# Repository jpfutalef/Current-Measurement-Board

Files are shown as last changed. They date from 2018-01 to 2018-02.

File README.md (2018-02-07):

# Power-Monitoring-Board
This repo contains scripts, details and specifications for a board designed to measure very low power consumption in MCU's with high accuracy.

## Goals

The goal here is to develop a simple current measuring board that can measure from 1uA - 50mA at high frequencies (>10kHz).

This board has to be easy to connect to a computer or a raspberry, minimizing cable connections. The idea is to have a single board with two usb ports, one to connect to the PC and the other to an IoT node with any usb connection (micro, mini, etc.).

## Organization

The repo is organized as follows,

* **ltspice**: in this folder can be found the different spice schematics to simulate the different current measurement boards.
* **scripts**: in this folder can be found different c, python, etc. scripts used to read data from the current measurement circuit or calibrate the respective board.
* **boards**: the actual eagle schematics can be found in this folder, either for the circuits or breakout's for small smd-components.

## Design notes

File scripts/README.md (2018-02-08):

# Scripts for usage in RIOT

These scripts are intended to be used with RIOT for power measurement using the power measurement board.

### adc_riot_test
Test RIOT's peripherial ADC, using a pause function to make a read with a fixed frequency. The user can set in the script the frequency, bit resolution, etc.

### arduino_ina226
INA226 IC was used to measure current with Arduino and the INA226_ADC.ino file inside this folder.

### power_measure
Necessary scripts for power measuring using the board. Includes a main file with makefile to flash into a micro-controller (Intended to be used with RIOT) and a master.py file to read values from computer via serial communication and make calculations.

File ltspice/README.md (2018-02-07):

# Spice models for power measurement boards
These spice models were used to simulate the behavior of the circuits before prototyping them. 

## About files
### v1_lmp2011_lt624X.asc
Simulates a LMP2011 based circuit. Uses LMP2011 as first stage. Uses LTC2041 for second stage in both ranges. Uses LTC2040 for supply buffer stage. Uses LT3461 as DC booster 8v68 supply for opamps.

### v1_ltc2055_lt624X.asc
Simulates a LTC2055 based circuit. Uses LTC2055 as first stage. Uses LTC2041 for second stage in both ranges. Uses LTC2040 for supply buffer stage. Uses LT3461 as DC booster 7V supply for opamps.

### v1_max4239_lt624X.asc
Simulates a MAX4239 based circuit. Uses MAX4239 as first stage. Uses LTC2041 for second stage in both ranges. Uses LTC2040 for supply buffer stage.

### v2_max4239_lt624X.asc
Added tolerance of more resistors, tries other shunt value. Reorganized and added labels for nodes.

### v3_max4239_lt624X.asc
Tries other shunt value. Changes stage gains to increase CMRR. Capacitor in SHDN now is connected to ground (as it should be).

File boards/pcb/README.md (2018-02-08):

## Power measurement boards

Until now, two board designs have been prototyped for the power measurement circuits, one based on LPM2011 op amp and the other one on MAX4239. This two IC were chosen because of their very low input offset voltage, both around 1uV or less in typical conditions. Also, both circuits in a similar fashion, this is detailed in the "How do they work" section.

Detailed design choices, specifications, BOM, versions, etc. are explained in the respective board folders.

## How do they work

### Current and voltage reading

It is very well known that for power measurement in circuits, voltage and current should be known.

Nowadays, analog-to-digital converters (ADC) are used widely to measure voltage, converting analog values in digital ones (bits), so they can be analyzed in a computer.

Current measurement is a bit harder, mainly because it's not possible to do it directly, instead, you should open the circuit, place a resistor (Shunt resistor) and, using Ohm's law, read the voltage across the Shunt to know the current.

After that, several subjects shall be considered:
- The voltage drop across the Shunt should not be too high, this can negatively impact in the supply of the circuit.

- It is better to isolate the voltage before an ADC input, these tend to produce peaks when a conversion is started changing the input impedance. A buffer amplifier stage might be placed.

- An important factor with ADC's are their least significant bit (LSB) value. That's the minimum voltage necessary to produce a reading in the ADC (one bit). It can also be considered as the ADC's resolution. The problem is that, when dealing with very low voltages, the LSB might be greater than the actual voltage that is intended to read, so the ADC will output a zero value. This can be solved by per-amplifying th ADC's input. The gain of the amplifier should be known so the actual reading can be computed.

- When dealing with very low currents, the voltage drop in the Shunt is also very low if the resistor is small. Just consider a 1 ohm resistor and 10 uA going trough it. According to Ohm's law, 10 uV will appear across the resistor leads. As it has been mentioned before, the LSB of the ADC might not be enough, so an amplifying stage should be placed. Here we have to deal with amplifiers limitations, specially input offset voltage. This is the voltage that appears between the differential inputs of the amplifiers when nothing is connected and depends among others on transistor paring in the ADC IC. A very precise op-amp should be chosen, with very low input offset voltage, like an auto-zero opamp.

- CMRR of opamp should also be considered, because for small currents the voltage across the shunt might have a very low common mode side that should be rejected. This can be solved with a configuration that produces a very high CMRR (120 dB or more) like instrumentation opamps. Never the less one must also be careful with the preición of the resistors used to define the opamp gain, as CMRR will be limited by the following expression:

<div align="center">
<a href="http://www.codecogs.com/eqnedit.php?latex=CMRR&space;=&space;\dfrac{A_d&plus;1}{4t}" target="_blank">CMRR = \dfrac{A_d+1}{4t}</a></div>

Where Ad is the differential gain of the amplifier and t the tolerance. It has been concluded that 0.1% tolerance resistor or more are OK.

### MAX4239 and LMP2011 boards

As explained above, amplifying stages and very low input offset voltage opamps are needed. The two boards proposed here use a very low input offset opamp in a first stage with differential configuration. A second stage uses a different opamp, with bigger input voltage but less noise.

This second stage takes the output of the first stage and amplifies depending of the current range. For very low current there is a high gain amplification and for high current a low gain amplification. Both amplification configurations of the second stage are implemented with a dual opamp (LTC6241) with very low noise. After this second stage an ADC measures the voltage that can be interpreted as a current measurement.

Due to the wide range of supply voltages that can power the target circuit, an ADC reads the voltage of the supply. For isolation, a buffer reducing stage is placed at the supply. This stage lowers the voltage 1/2 times so it can be read by an ADC with 3.3V reference, therefore the circuit could also properly read 5V supply.

### Calibration

Even though this opamps have very low input voltage, with very low currents (5uA or less) the voltage drop in the shunt has the same order of magnitude as it's offset.

A set of calibration resistors are used to emulate the conversion of low current values and after establish a piecewise approximation for these voltage ranges. This is why there are 4 fixed resistor values (1k, 10k, 100k and 1M) and 4 analog switches.

There is also an analog switch that allows the flow of current trough the target circuit. The purpose of this switches is to make a calibration of the readings before using the board, by not allowing current flow trough the target circuit and connecting the resistors one by one.

### High-side current measurement and low-side current measurement

Depending of the configuration, the shunt resistor could be placed at the top, just after the supply (high-side current measurement) or at the bottom, just before ground (low-side current measurement). In this case, high-side current measurement has been chosen because it does not intervene the ground path of the circuit.

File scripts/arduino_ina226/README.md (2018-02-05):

## Simple INA226 test

This file contains a library to test INA226. This IC was initially considered to measure current, voltage and power.

### Benefits of INA226

The ina226 has everything integrated into 1 IC (current measuring circuit, ADC & i2c interface) which makes it easy to connect and setup.

### Limitations of INA226

The fact that it only has an integrated ADC limits the resolution for this IC to the defined gain for the single transimpedance amplifier stage. For example assuming 5V supply for the ADC and a max current on 100mA max resolution would be of 15,23 uA/LSB. Plus the voltage input range is fixed at -81.8175 mV to 81.92 mV this limits the shunt resistor value.

Although having great features we miss in this IC the possibility to connect an extra gin stage to have better resolution for lower current ranges, this is why this IC was finally discarded.

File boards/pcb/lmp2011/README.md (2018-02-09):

# PCB eagle schematics and boards for LMP2011

LMP2011 is a precision OPAMP. This device uses auto-zero techniques to continually correct the input offset error voltage. The input offset is 60uV in the worst case scenario,  0.8uV typically. Furthermore has a typical CMRR of 130dB, its minimum is 95dB.

## Notations
* Current Measuring Board (CMB): PCB with the designed circuit that can measure shunt voltage, and supply voltage.
* mcu: microcontroller connected to the CMB, its performs calibrations and translate the supply voltage and current measurements.
* Node: target mcu which power consumption the CMB is measuring.

## How to use

* Connect switch controllers (SWITCH_CTRL_1 to SWITCH_CTRL_5) to 5 different GPIO on any mcu.
* Connect low current, high current and supply voltage to 3 different ADC input in the mcu
* Power the CMB, either from the micro usb port or with 5V from an external power supply
* Bypass the targeted node power supply by either connecting it's power source to VBAT or the USB port on CMB.
* If the targeted node supply source is connected to VBAT then the node can be powered by connecting it's power input to VMCU, if it's USB powered a jumper must be connected between 5V and VBAT on CMB.

## Specifications:
- Power supply: 5V from USB port
- Current range: ~10uA - 50mA
- First stage gain: x100
- Second stage gain: x197 for low current, x1.51 for high current

## How version 2 works(detailed)

This board has a similar operation as the design using MAX4239, except that in this case the CMB does not include a DC booster (TODO: check if it is neccesary).

### Fist stage

The first stage amplifies the voltage difference in the shunt resistance through an OPAMP. R1, R2, R4 and R5 form a x100 gain between VBAT y VS-. R27 and C2 are added for stability purposes. 

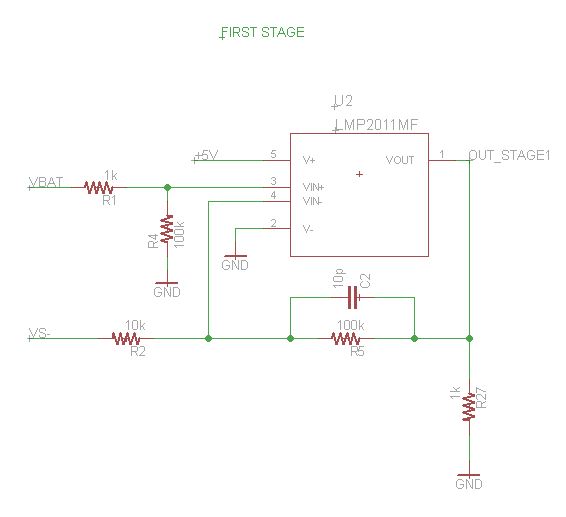
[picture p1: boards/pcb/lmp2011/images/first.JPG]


### Second stage

The second stage has a LTC6241 high precision dual opamp. There are two current ranges with different gains:

- Low current range: 0uA-600uA, x197 gain
- High current tange: 600uA-50mA, x1.51 gain

These gains values adjust to the ADC input ranges. The 49.9 resistor are put in place to isolate the amplifier output and ADC input, thus preventing oscillation.

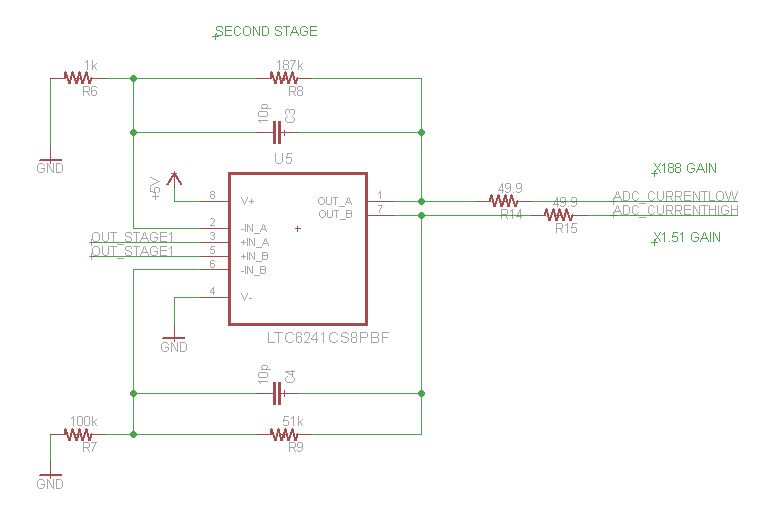
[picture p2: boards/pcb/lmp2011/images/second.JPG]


4 usually open analog switches are used for calibration in low current, this is done by measuring current flow threw resistors R9, R10, R13 and R14. TS5A23166DCUR switches where chosen for their high voltage input range, high max current and low Ron (0.8 ohms).

A normally closed switch is connected between the target node and it's supply source. The TS5A23167DCUR was chosen with similar characteristics as the TS5A23167DCUR.

C1 capacitor is connected between the supply source and ground to stabilize supply voltage from power source.

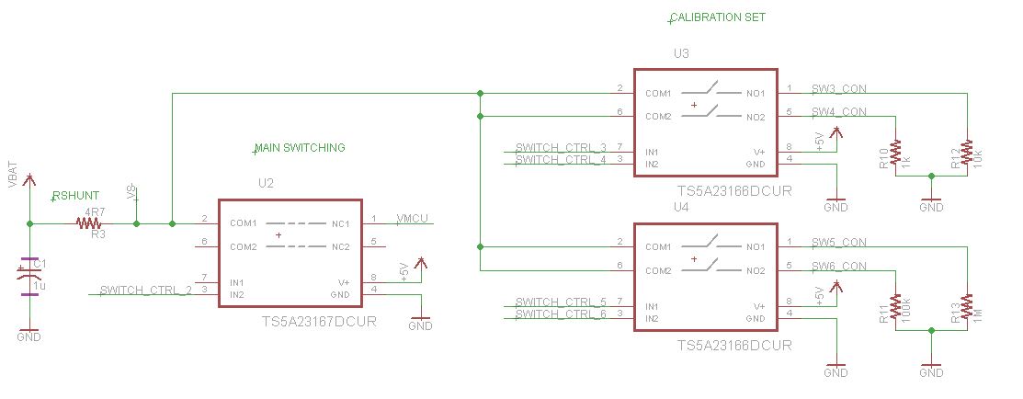
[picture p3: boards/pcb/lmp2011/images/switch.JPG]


The buffer stage to measure the supply source uses a LTC6240 high precision amplifier with a x0.5 gain stage to allow supply voltage higher than the mcu supply (3.3V) to be converted with the ADC. This buffer stages also isolated the two.

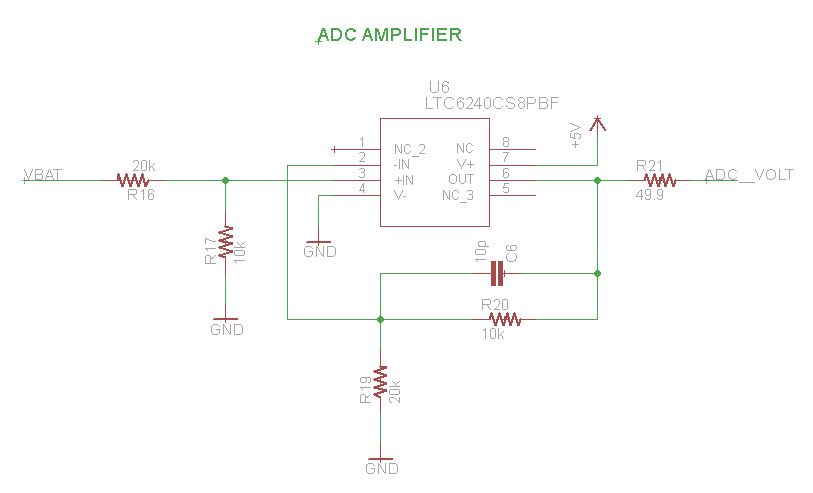
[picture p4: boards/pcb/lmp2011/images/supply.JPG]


As a supply source a microUSB type B female connector is used. This gives a 5V power supply. To reduce high frequency noise a high impedance, low frequency ferrite is used (1K@1Mhz).

A female type A USB connector can be used to power the targeted node. Analog and digital ground are separated by using two schottky diodes, CUS08F30 because of their high response and low activation voltage.

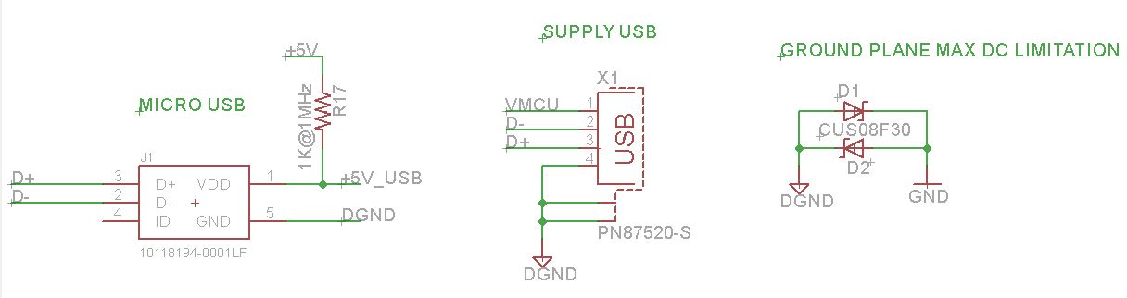
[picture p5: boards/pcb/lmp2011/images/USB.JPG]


### Available connections

Multiple input/output pins are exposed to users: 

- SWITCH_CTRL_1: switch's on power supply for targeted node.
- SWITCH_CTRL_2 a 5: switches on or off calibration resistors.
- VMCU: output voltage that powers the targeted node it's short-circuited to the female type A USB.
- GND: ground
- OUT_STAGE1: first amplifying stage gain output, for debugging purposes.
- VS-: shunt resistor low voltage pin.
- VBAT: pin where targeted node supply voltage is connected to bypass it.
- +5V: 5V output, its separated from the USB by the ferrite. de 5V, separada de USB por la ferrita.

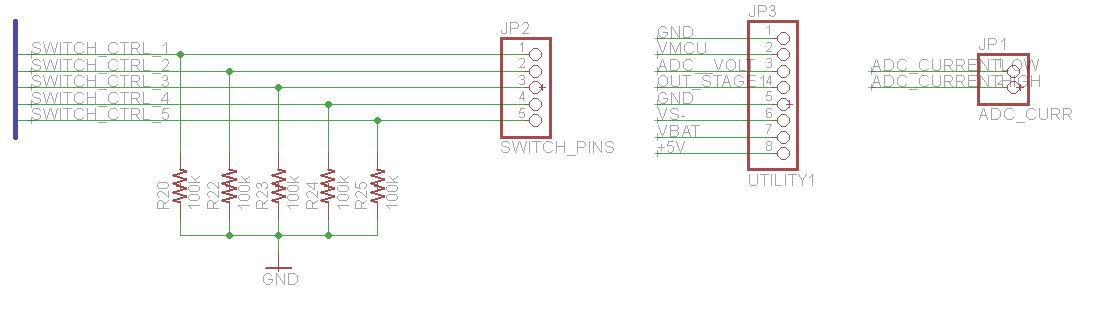
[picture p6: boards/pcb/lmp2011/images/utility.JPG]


# Board versions

## LMP2011 V1 - Fabricated
This version of the board was manufactured with [OSHPARK](https://oshpark.com/). Soldering and testing was done at Inria Chile office.

### Overview

This board needs a 5V supply for most of the IC, LMP2011 get supply from a DC booster in the CMB.

The first stage is a differential amplifier with x10 gain, the second stage has a low current stage with x197 gain and a high current range with x1.51 gain.

To read supply voltage a x0.5 buffer stage is used.

Analog and digital ground are separate with schottky diodes.

5V supply source is filtered with a 1k@1MHz ferrite.

USB enclosure is connected to the digital ground.

### Testing conclusions

#### Remarks
- Manufactured board
- Soldered components
- All IC had correct supply and GND connections
- There is an error in power supply for the LMP2011 design: it can't be supply from 8v68. MIC2250 is not connected and bypass 5V to the supply pin of the IC.
- There aren't conclusive results from the circuit. The CMB with this IC does not work as it should, neither in a breadboard.

#### TODO
- Check connections in LMP2011
- Check real measurement range
- Make reading with a mcu. Calibrate and control of the switches

#### Issues
- LMP2011 not working correctly
- The gain in low current stage should be x197, not x19.7 10K resistance should be a 1K
- Control switch for node supply are not connected well. This was fixed soldering directly from the inputs of the switch
- Ad
- VBAT and VADC silkscreen names are misplaced, they are switched.
- There are no pull-down resistors in the control switch

#### To improve
- CMRR by using higher tolerance resistor values, at least 0.1%. This can also be done by incrementing the stages gain, but this affects the current ranges
- Change USB port from SMD to thru-hole to improve robustness in the pcb
- Different configurations for the first stage should be considered

## LMP2011 V2 - not manufactured

This version of the board should solve the issues from the last version manufactured.

* Remove DC booster (Check supply needed from the IC)
* Low current gain is addressed by changing 10K resistors to 1K
* Switch connection is fixed
* Pull down resistors are included for the switches

There is only the schematic for this board, not the board design yet

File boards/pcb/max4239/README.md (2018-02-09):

# PCB eagle schematics and boards for MAX 4239

MAX4239 is a auto-zero amplifier, with low input voltage offset of 1.0uV (typical) and 2uV (full temp range), it also has a high CMRR of 120dB (min), 140dB (typ).

### Notations
* Current Measuring Board (CMB): PCB with the designed circuit that can measure shunt voltage, and supply voltage.
* mcu: microcontroller connected to the CMB, its performs calibrations and translate the supply voltage and current measurements.
* Node: target mcu which power consumption the CMB is measuring.

### How to use

* connect switch controllers (SWITCH_CTRL_1 to SWITCH_CTRL_5) to 5 different GPIO on any mcu.
* connect the low current, high current and supply voltage output to 3 different ADC inputs on your mcu.
* power the CMB by either connecting it to it's microUSB port ore the 5V supply pin.
* bypass the targeted node power supply by either connecting it's power source to VBAT or the USB port on CMB.
* if the targeted node supply source is connected to VBAT then the node can be powered by connecting it's power input to VMCU, if it's USB powered a jumper must be connected between 5V and VBAT on CMB.

### Ratings V2:
- Power supply: 5V from USB port
- Current range(ideal): ~1uA - 50mA
- First stage gain x10
- Second stage gain x197 for low currents and x1.51 for high currents.

### Ratings V3:
- Power supply: 5V from USB
- Current range(ideal): ~1uA - 50mA
- First stage gain x100
- Second stage gain x19.7 for low currents and x0.151 for high currents.

### MAX4239 V3 (detailed)

The first stage amplifies the voltage measured at the shunt by applying a differential gain. R1, R2, R4 & R5 form a x100 gain. R6 and C3 are added for stability, C3 also helps to reduce currents peaks. C2 stabilizes the power supply.

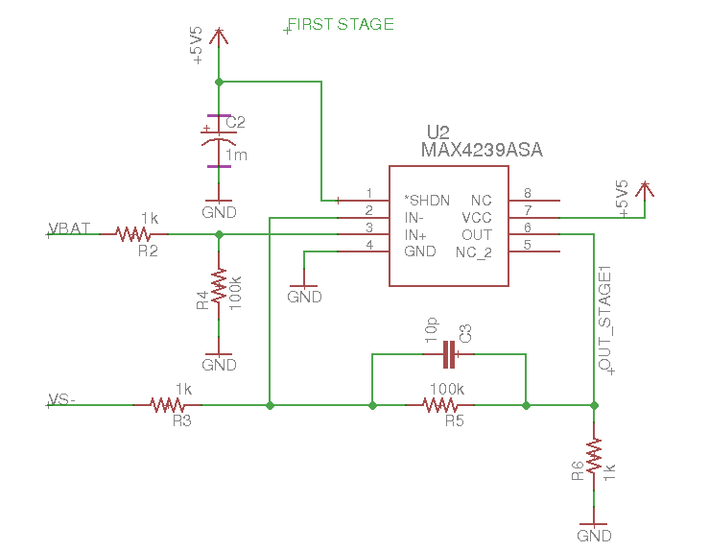
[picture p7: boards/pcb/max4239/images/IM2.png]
max4239_gain_stage


The second stage is conformed by a dual LTC6241 high precision opamp. There are two current ranges with to different gains:

- Low current range: 0uA-600uA, x197 gain
- High current range: 600uA-50mA, x 1.51 gain

These gains values adjust to the ADC input ranges. The 49.9 resistor are put in place to isolate the amplifier output and the ADC input, thus preventing oscillation.

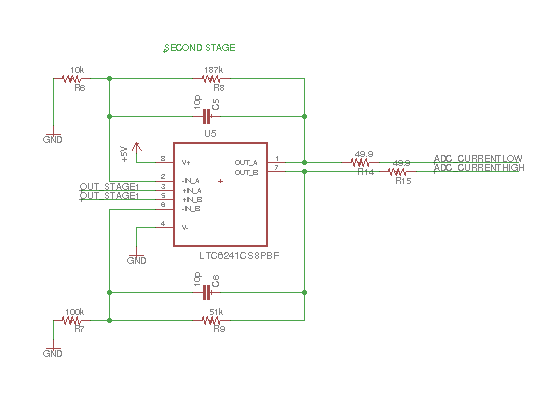
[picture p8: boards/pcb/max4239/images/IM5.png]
ltc6241_gain_stage


4 usually open analog switches are used for calibration in low current, this is done by measuring current flow threw resistors R9, R10, R13 and R14. TS5A23166DCUR switches where chosen for their high voltage input range, high max current and low Ron (0.8 ohms).

A normally closed switch is connected between the target node and it's supply source. The TS5A23167DCUR was chosen with similar characteristics as the TS5A23167DCUR.

C1 capacitor is connected between the supply source and ground to stabilize supply voltage from power source.

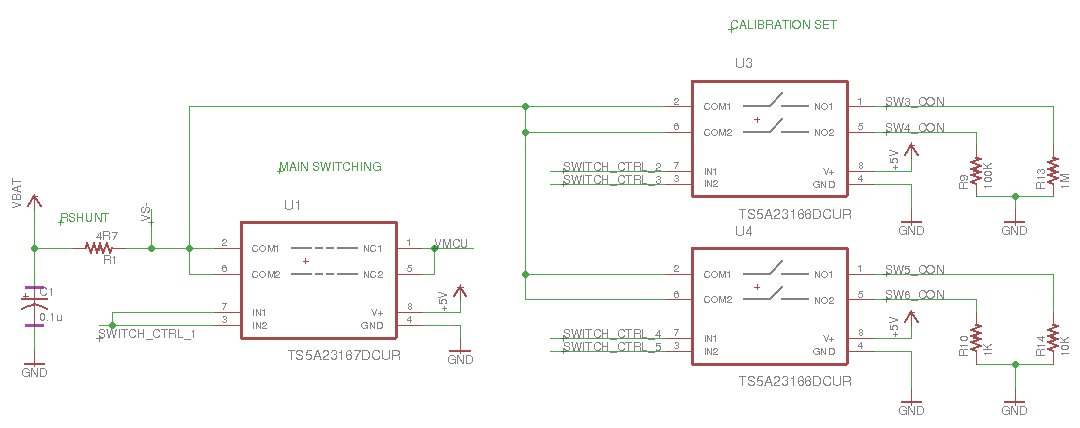
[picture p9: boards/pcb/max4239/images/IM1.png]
switches


The buffer stage to measure the supply source uses a LTC6240 high precision amplifier with a x0.5 gain stage to allow supply voltage higher than the mcu supply (3.3V) to be converted. This buffer stages also isolated the two.

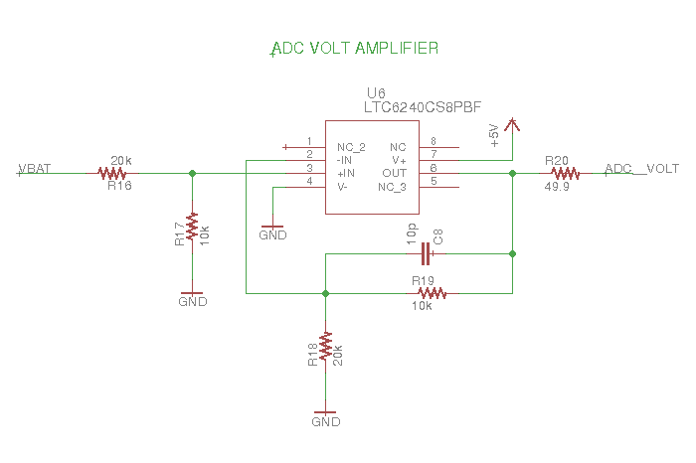
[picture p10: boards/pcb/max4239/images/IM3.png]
voltage_buffer


As a supply source a microUSB type B female connector is used. This supply a 5V power supply. To reduce high frequency noise a high impedance, low frequency ferrite is used (1K@1Mhz).

A female type A USB connector can be used to power the targeted node. Analog and digital ground are separated by using two schottky diodes, CUS08F30 because of their high response and low activation voltage.

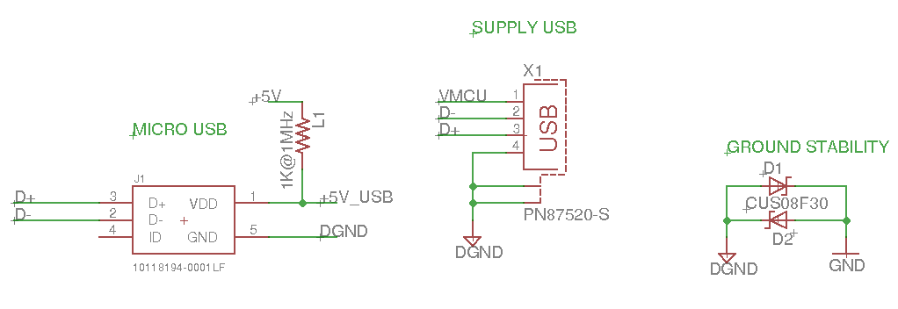
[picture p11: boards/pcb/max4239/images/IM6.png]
power_supply_sources


Multiple input/output pins are supplied (R21 to R25 are pull down resistors so calibration resistors and node supply are normally turned off). These are:

- SWITCH_CTRL_1: switch's on power supply for targeted node.
- SWITCH_CTRL_2 a 5: switches on or off calibration resistors.
- VMCU: output voltage that powers the targeted node it's short-circuited to the female type A USB.
- GND: ground
- OUT_STAGE1: first amplifying stage gain output, for debugging purposes.
- VS-: shunt resistor low voltage pin.
- VBAT: pin where targeted node supply voltage is connected to bypass it.
- +5V: 5V output, its separated from the USB by the ferrite.

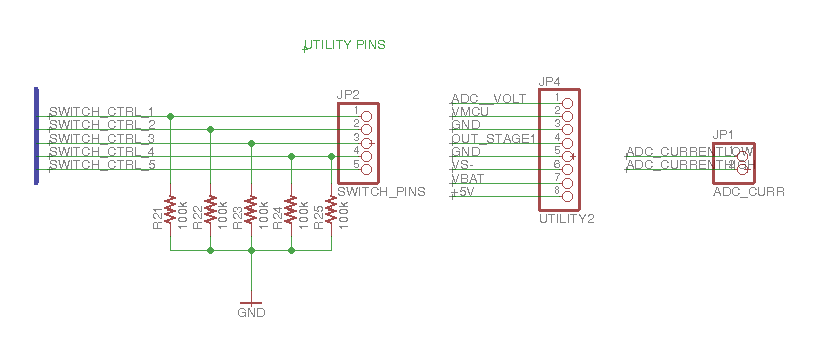
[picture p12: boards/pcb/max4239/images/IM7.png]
input_output_pins


MAX4239 maximum supply voltage is 6V & it's differential inputs can only take inputs 0.3V bellow its supply voltage. It has been observed that for 5V inputs in one of the differential inputs the MAX4239 voltage output oscillates. This is fixed by using a MIC2250 booster to boost supply to 5.5 volts. The configurations used is the one recommended by manufacturer.

max4239_supply_boost

# Board versions

## MAX4239 V1 (not fabricated)

Schematic is almost the same as version 2, in terms of functionalities. It just has a bigger size and laxer design rules.

## MAX4239 V2 (fabricated)

This board version was fabricated with oshpark. Soldering and testing was done at Inria Chile IoT-LAb.

### Details

This board version considers a 5V supply for all IC which is supplied by the microUSB connector.

The first stage is a differential amplifier with x10 gain, the second stage has a low current stage with x197 gain and a high current range with x1.51 gain.

To read supply voltage a x0.5 buffer stage is used.

Analog and digital ground are separate with schottky diodes.

5V supply source is filtered with a 1k@1MHz ferrite.

USB enclosure is connected to the digital ground.

### Prototyping and testing conclusion

#### Remarks
- manufactured board
- soldered components, ok
- all IC had correct supply and GND connections
- testing consumption with different loads currents from 600uA to 50mA have been correctly measured, lower current values can be measured but it calibration valued haven't been checked
- calibrations values have been obtained, fidelity of the calibrated readings hasn't been verified

#### TODO
- Verify effective measuring range.
- Verify the whole pipeline from mcu to node.
- A new version that solves all V2 issues but doesn't change the stages gain should be implemented.

#### Issues
- When a 5V power supply is used for the first gain stage some oscillations have appeared. The problem was solved using a 5.5V supply for this stage (or higher).
- C2 condenser was wrongly placed. It can be removed at it's shorted for the board to work.
- The first low current gain stage should be 197 and not 19.7, the 1k resistor should be changes by a 10k resistor.
- Targeted node power control switches are wrongly connected. This was fixed by soldering the two inputs for these switches. (the right one was not connected do SWITCH_CTRL_1).
- Pull-down resistors so default calibration resistors and power targeted node supply is off.
- VBAT and VMCU silkscreen names are misplaced, they are switched.

#### To improve
- CMRR by using higher tolerance resistor values, at least 0.1%. This can also be done by incrementing the stages gain, but this affects the current ranges
- In the fabricated board the supply switch pins must be soldered to allow proper enabling and disabling of these (this is not the case for V3)
- Different configurations for the first stage should be considered

## MAX4239 V3 (not fabricated)

This version addressed all the issues pointed out for V2
* DC booster is used to bump MAX4239 power source from 5V to 5.5V
* C2 is correctly placed
* Low current gain is addressed by changing 10K resistors to 1K
* Switch connection is fixed
* Pull down resistors are included for the switches

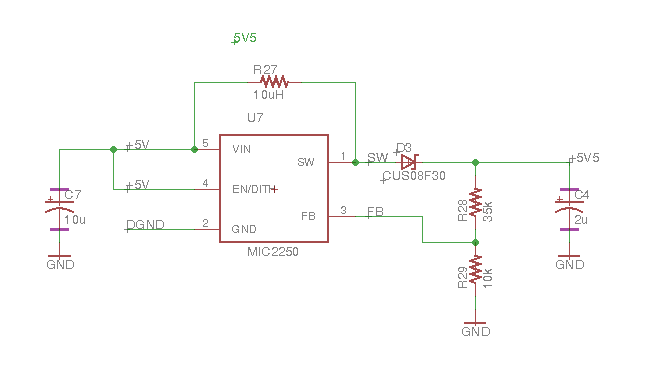
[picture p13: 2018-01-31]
boards/pcb/max4239/images/IM4.png

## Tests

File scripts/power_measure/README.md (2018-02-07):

# Power measurement Scripts

This folder contains resources to control the measuring node and register different current measurements. The files contained here are:

* **master.py**: python script that controls the measure_node. It opens a serial terminal, reads/receives calibration values from the node, and proceeds to specify sampling rate for the node. Measured values (ADC voltage readings) are transformed to current  values.

* **measure_node**: contains c code based on RIOT to flash on node. It's assumes that RIOT is in the same directory as this repo.

## Future work

As of now master.py just captures serial data but isn't logging it anywhere. This should be interfaced/adapted to work with FIT IoT-Lab code or other.

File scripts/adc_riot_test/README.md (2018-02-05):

# ADC test in RIOT

Initial current measurement test scripts.

Avoids using xtimer_sleep since current master version (2018.01-branch) is broken for nucleo32-l031, instead custom pause(milliseconds) is used.

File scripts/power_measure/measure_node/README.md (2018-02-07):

## Measure node code

This directory contains all files required to generate the bin for the measure node. This code is RIOT based and assumes RIOT to be at the following location: "$(CURDIR)/../../../../RIOT".

#### Requirements

* RIOT installed at "$(CURDIR)/../../../../RIOT", if not change in Makegile
* [RIOT](https://github.com/RIOT-OS/Tutorials) & dependencies installed, usefull install [script](https://github.com/jia200x/RIOT-scripts)
* nucleo-l031 or any board with at least 3 ADC pins and 5 GPIO.
* [current_meas_board](https://github.com/jpfutalef/Current-Measurement-Board/tree/master/boards/PCB)

####  How to use
To program, flash compile run ```make clean all -j flash term```. This opens up a serial terminal, type ```help``` to view available commands.

Calibration functions are designed to work with master.py, it doesn't adjust read values locally but delegates this burden to it's serial interlocutor.

For now the only supported board is nucleo-l031, but only in reason of the defined GPIO and adc pins, this can be added manually to the code.

#### Brief explanation

This is the basic flow established by the code:

    1.- Checks if valid gpio, adc lines, etc..
    2.- Turns of calibration resistors, enables MCU power.
    3.- Starts shell
        3.1.- Calibrate: ```meas calibrate```, prints calibrations results to terminal, for this it has to turn off MCU, and sequentially enable and measure current for each calibration resistor.
        3.2.- Read: ```meas start```, start reading from both current ranges (high & low) and supply voltage.
        3.3- Set: sample frequency and ADC resolution can be changes by calling ```meas set freq|res```

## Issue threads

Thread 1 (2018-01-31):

MAX4239 Vol limit

fjmolinas, 2018-01-31:
MAX 4239 has a minimum voltaje output low of 4mA.

This means that 0 current passing threw the shunt resistor will still show 4mA on output and after gain stages might saturate output with x200 gain.

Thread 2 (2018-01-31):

Resistor Precision

fjmolinas, 2018-01-31:
Currently used resistor have a precision around 1% or 0.5%, for correct opam gain at least 0.1% is needed.

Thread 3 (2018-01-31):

python doesn't capture serial output

fjmolinas, 2018-01-31:
AOTM the python scrypt to transform calibrated values and read current measurement doen't capture or parse node output correctly.

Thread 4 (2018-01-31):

MAX4239 PCB

fjmolinas, 2018-01-31:
The first PSB fabricated oscilates when 5V are at V+ differential since it's to close to designed supply  voltage of 5V, this was corrected in the newest eagle schematic.

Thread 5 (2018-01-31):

LMP2011 doesn't work right

fjmolinas, 2018-01-31:
We weren't able to make LMP2011 work on either a breakout or the hole circuit measurement board. There is a known problem in older PCB version where supply voltage was higher than the 5.8 V, this was a design error.

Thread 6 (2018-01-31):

LMP2011 PCB circuit

fjmolinas, 2018-01-31:
The pcb circuit that was fabricated had a design flaw in the sense that the PCB had USB port functionality inverted, this can be fixed if using a male to male USB conector.

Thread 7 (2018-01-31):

Feature Improovements

fjmolinas, 2018-01-31:
* Try different IC for first stage gain, (LTC6102)
* 12 bits ADC is enough with the stage gain, but beter ADC mean better resolution current wise, this should e
included.
* USB multiplexer could be used so there is no need for an extra UART com cable between RPI/PC and board.

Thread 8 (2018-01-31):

Fabricated PCB has wrong stencil in pinout

fjmolinas, 2018-01-31:
MAX4239 and LPM2011 had inverted pins of VBAT and VADC.

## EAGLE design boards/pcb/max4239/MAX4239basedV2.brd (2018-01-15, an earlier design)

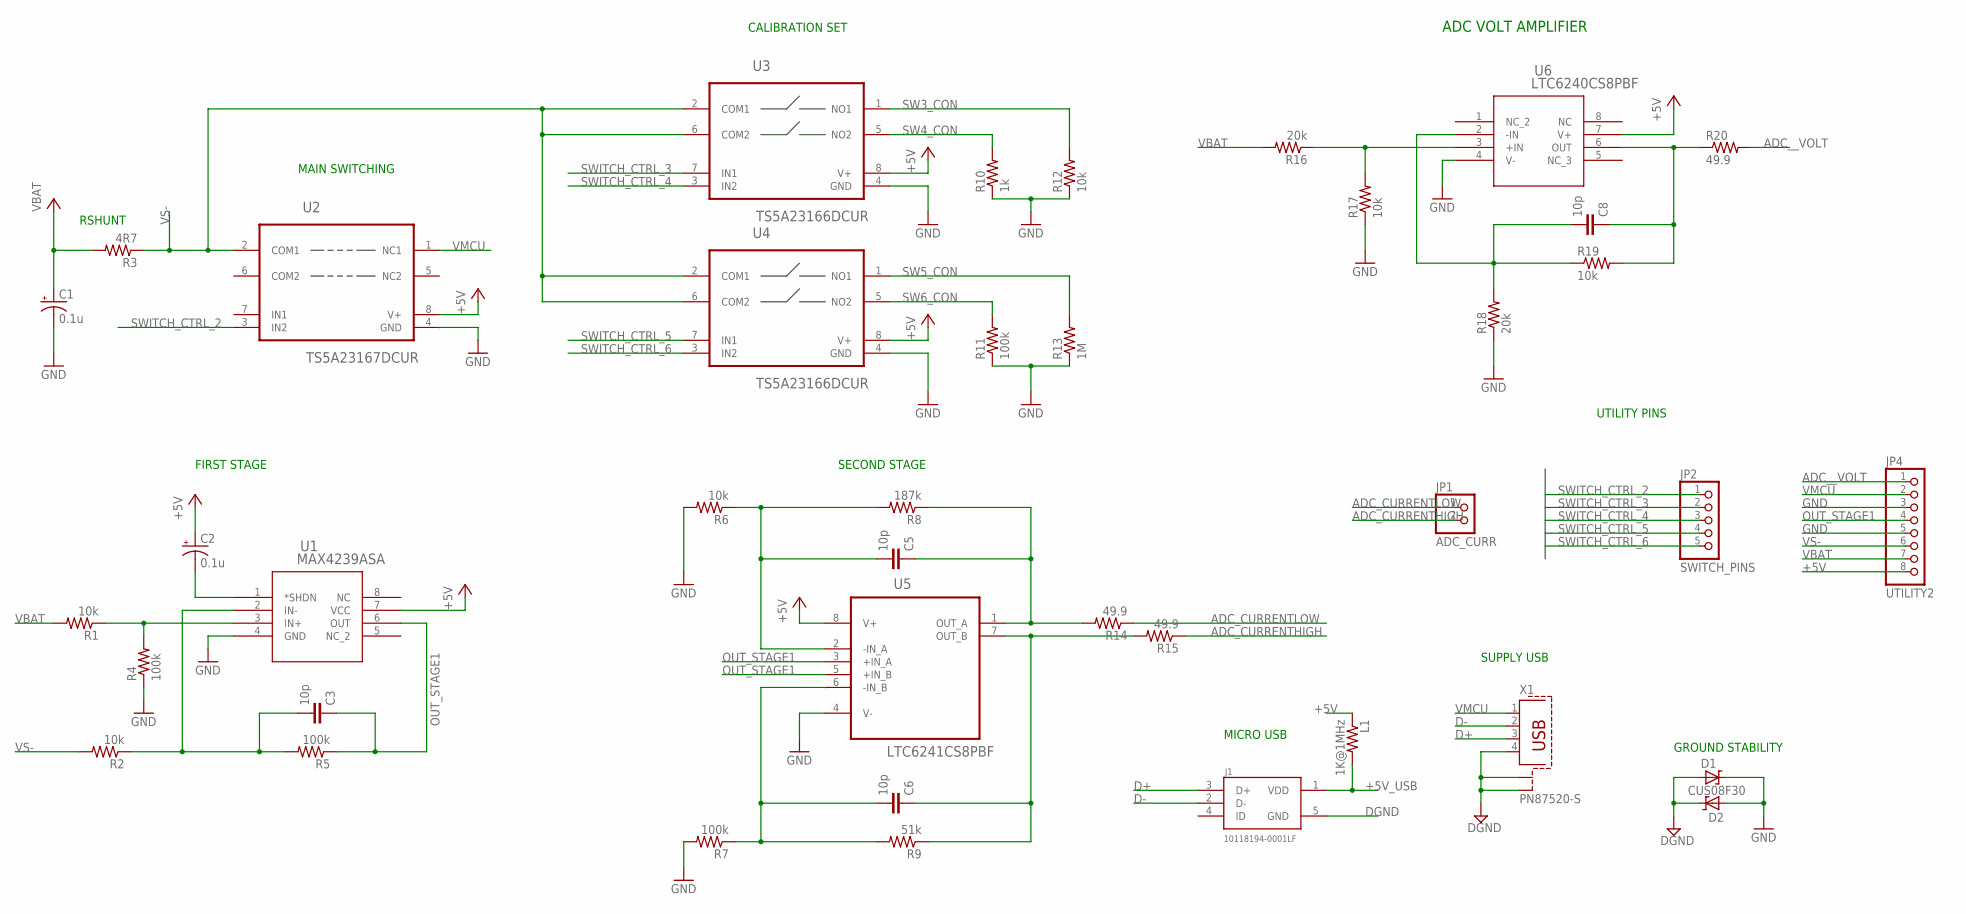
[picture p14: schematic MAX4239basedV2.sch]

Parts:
C1, C2: 0.1u; PANASONIC_B
C3, C5, C6, C8: 10p; C0805
D1, D2: CUS08F30; SOD323
J1: 10118194-0001LF; FRAMATOME_10118194-0001LF
JP1: ADC_CURR; 1X02
JP2: SWITCH_PINS; 1X05
JP4: UTILITY2; 1X08
L1: 1K@1MHz; R0805
R1, R2, R6, R12, R17, R19: 10k; R0805
R3: 4R7; R0805
R4, R5, R7, R11: 100k; R0805
R8: 187k; R0805
R9: 51k; R0805
R10: 1k; R0805
R13: 1M; R0805
R14, R15, R20: 49.9; R0805
R16, R18: 20k; R0805
U1: MAX4239ASA; 21-0041B_8
U2: TS5A23167DCUR; SOP50P310X90-8N
U3, U4: TS5A23166DCUR; SOP50P310X90-8N
U5: LTC6241CS8PBF; SOIC127P600X175-8N
U6: LTC6240CS8PBF; SO-8_S
X1: PN87520-S

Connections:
+5V: C2.+, JP4.8, L1.1, U1.7 (VCC), U2.8 (V+), U3.8 (V+), U4.8 (V+), U5.8 (V+), U6.7 (V+)
+5V_USB: J1.1 (VDD), L1.2
ADC_CURRENTHIGH: JP1.2, R15.1
ADC_CURRENTLOW: JP1.1, R14.1
ADC__VOLT: JP4.1, R20.2
D+: J1.3 (D+), X1.3
D-: J1.2 (D-), X1.2
DGND: D1.A, D2.C, J1.5 (GND), X1.4, X1.S1, X1.S2
GND: C1.-, D1.C, D2.A, JP4.3, JP4.5, R4.1, R6.2, R7.2, R10.1, R11.1, R12.1, R13.1, R17.1, R18.1, U1.4 (GND), U2.4 (GND), U3.4 (GND), U4.4 (GND), U5.4 (V-), U6.4 (V-)
unnamed: R16.1, R17.2, U6.3 (+IN)
unnamed: C8.1, R19.2, R20.1, U6.6 (OUT)
unnamed: C8.2, R18.2, R19.1, U6.2 (-IN)
unnamed: C5.1, R8.1, R14.2, U5.1 (OUT_A)
unnamed: C2.-, U1.1 (*SHDN)
unnamed: C3.2, R2.1, R5.2, U1.2 (IN-)
unnamed: C6.1, R9.1, R15.2, U5.7 (OUT_B)
unnamed: R1.1, R4.2, U1.3 (IN+)
unnamed: C5.2, R6.1, R8.2, U5.2 (-IN_A)
unnamed: C6.2, R7.1, R9.2, U5.6 (-IN_B)
OUT_STAGE1: C3.1, JP4.4, R5.1, U1.6 (OUT), U5.3 (+IN_A), U5.5 (+IN_B)
SW3_CON: R12.2, U3.1 (NO1)
SW4_CON: R10.2, U3.5 (NO2)
SW5_CON: R13.2, U4.1 (NO1)
SW6_CON: R11.2, U4.5 (NO2)
SWITCH_CTRL_2: JP2.1, U2.3 (IN2)
SWITCH_CTRL_3: JP2.2, U3.7 (IN1)
SWITCH_CTRL_4: JP2.3, U3.3 (IN2)
SWITCH_CTRL_5: JP2.4, U4.7 (IN1)
SWITCH_CTRL_6: JP2.5, U4.3 (IN2)
VBAT: C1.+, JP4.7, R1.2, R3.2, R16.2
VMCU: JP4.2, U2.1 (NC1), X1.1
VS-: JP4.6, R2.2, R3.1, U2.2 (COM1), U3.2 (COM1), U3.6 (COM2), U4.2 (COM1), U4.6 (COM2)

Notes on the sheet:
ADC VOLT AMPLIFIER
CALIBRATION SET
MAIN SWITCHING
FIRST STAGE
SECOND STAGE
RSHUNT
SUPPLY USB
MICRO USB
UTILITY PINS
GROUND STABILITY

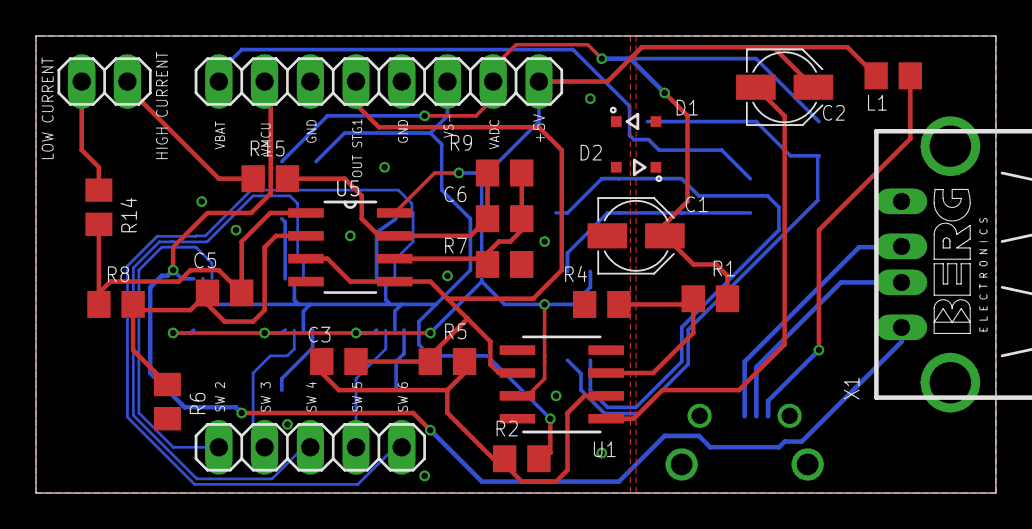
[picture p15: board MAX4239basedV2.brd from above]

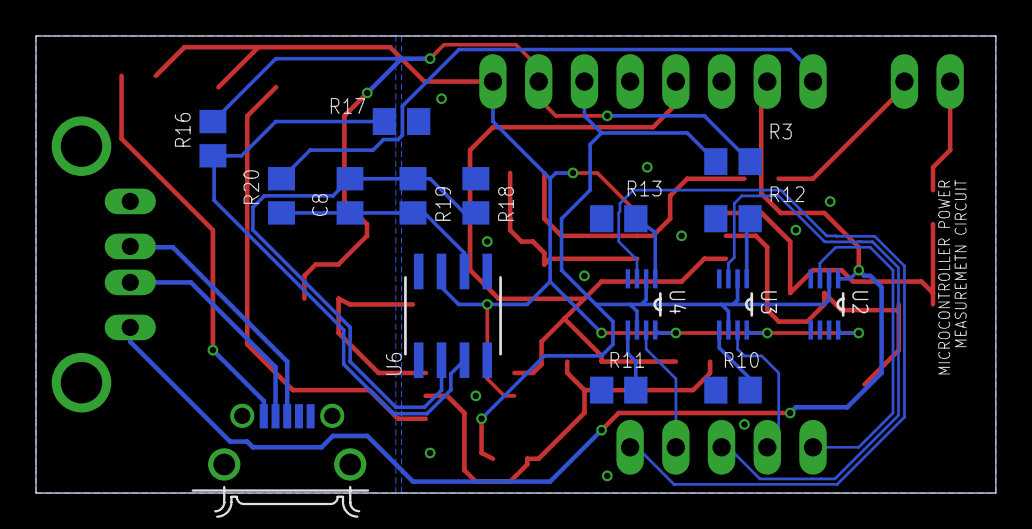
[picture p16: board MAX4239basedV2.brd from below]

Board: 2 copper layers, 53.3 x 25.4 mm, 40 parts (16 on the bottom side), 32 nets.

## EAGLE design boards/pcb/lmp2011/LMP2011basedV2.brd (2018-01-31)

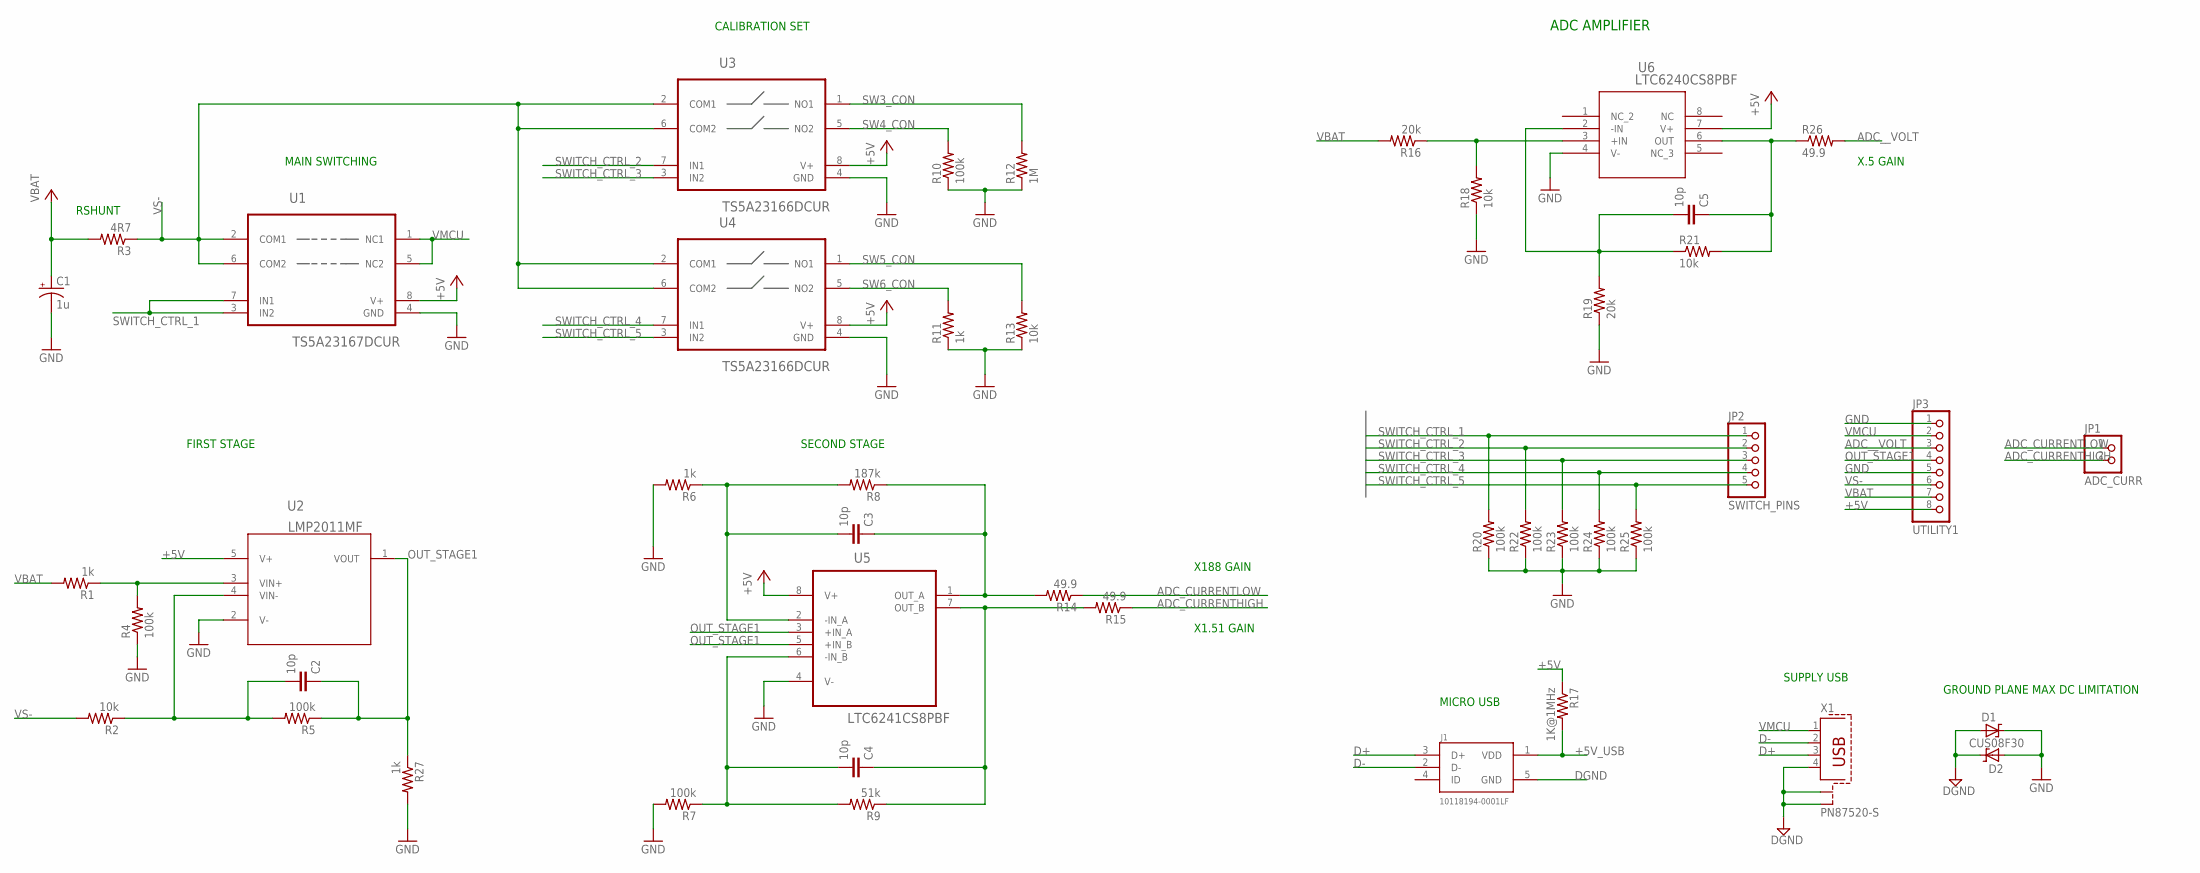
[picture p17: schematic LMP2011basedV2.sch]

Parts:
C1: 1u; PANASONIC_B
C2, C3, C4, C5: 10p; C0805
D1, D2: CUS08F30; SOD323
J1: 10118194-0001LF; FRAMATOME_10118194-0001LF
JP1: ADC_CURR; 1X02
JP2: SWITCH_PINS; 1X05
JP3: UTILITY1; 1X08
R1, R6, R11, R27: 1k; R0805
R2, R13, R18, R21: 10k; R0805
R3: 4R7; R0805
R4, R5, R7, R10, R20, R22, R23, R24, R25: 100k; R0805
R8: 187k; R0805
R9: 51k; R0805
R12: 1M; R0805
R14, R15: 49.9; R0805
R16, R19: 20k; R0805
R17: 1K@1MHz; R0805
R26: 49.9; R0603
U1: TS5A23167DCUR; SOP50P310X90-8N
U2: LMP2011MF; SOT95P285X120-5N
U3, U4: TS5A23166DCUR; SOP50P310X90-8N
U5: LTC6241CS8PBF; SOIC127P600X175-8N
U6: LTC6240CS8PBF; SO-8_S
X1: PN87520-S

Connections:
+5V: JP3.8, R17.1, U1.8 (V+), U2.5 (V+), U3.8 (V+), U4.8 (V+), U5.8 (V+), U6.7 (V+)
+5V_USB: J1.1 (VDD), R17.2
ADC_CURRENTHIGH: JP1.2, R15.1
ADC_CURRENTLOW: JP1.1, R14.1
ADC__VOLT: JP3.3, R26.2
D+: J1.3 (D+), X1.3
D-: J1.2 (D-), X1.2
DGND: D1.A, D2.C, J1.5 (GND), X1.4, X1.S1, X1.S2
GND: C1.-, D1.C, D2.A, JP3.1, JP3.5, R4.1, R6.2, R7.2, R10.1, R11.1, R12.1, R13.1, R18.1, R19.1, R20.1, R22.1, R23.1, R24.1, R25.1, R27.2, U1.4 (GND), U2.2 (V-), U3.4 (GND), U4.4 (GND), U5.4 (V-), U6.4 (V-)
unnamed: R16.1, R18.2, U6.3 (+IN)
unnamed: C5.1, R21.2, R26.1, U6.6 (OUT)
unnamed: C5.2, R19.2, R21.1, U6.2 (-IN)
unnamed: C3.1, R8.1, R14.2, U5.1 (OUT_A)
unnamed: C2.2, R2.1, R5.2, U2.4 (VIN-)
unnamed: C4.1, R9.1, R15.2, U5.7 (OUT_B)
unnamed: R1.1, R4.2, U2.3 (VIN+)
unnamed: C3.2, R6.1, R8.2, U5.2 (-IN_A)
unnamed: C4.2, R7.1, R9.2, U5.6 (-IN_B)
OUT_STAGE1: C2.1, JP3.4, R5.1, R27.1, U2.1 (VOUT), U5.3 (+IN_A), U5.5 (+IN_B)
SW3_CON: R12.2, U3.1 (NO1)
SW4_CON: R10.2, U3.5 (NO2)
SW5_CON: R13.2, U4.1 (NO1)
SW6_CON: R11.2, U4.5 (NO2)
SWITCH_CTRL_1: JP2.1, R20.2, U1.3 (IN2), U1.7 (IN1)
SWITCH_CTRL_2: JP2.2, R22.2, U3.7 (IN1)
SWITCH_CTRL_3: JP2.3, R23.2, U3.3 (IN2)
SWITCH_CTRL_4: JP2.4, R24.2, U4.7 (IN1)
SWITCH_CTRL_5: JP2.5, R25.2, U4.3 (IN2)
VBAT: C1.+, JP3.7, R1.2, R3.2, R16.2
VMCU: JP3.2, U1.1 (NC1), U1.5 (NC2), X1.1
VS-: JP3.6, R2.2, R3.1, U1.2 (COM1), U1.6 (COM2), U3.2 (COM1), U3.6 (COM2), U4.2 (COM1), U4.6 (COM2)

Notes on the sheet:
ADC AMPLIFIER
CALIBRATION SET
MAIN SWITCHING
FIRST STAGE
SECOND STAGE
RSHUNT
SUPPLY USB
MICRO USB
GROUND PLANE MAX DC LIMITATION
X188 GAIN
X1.51 GAIN
X.5 GAIN

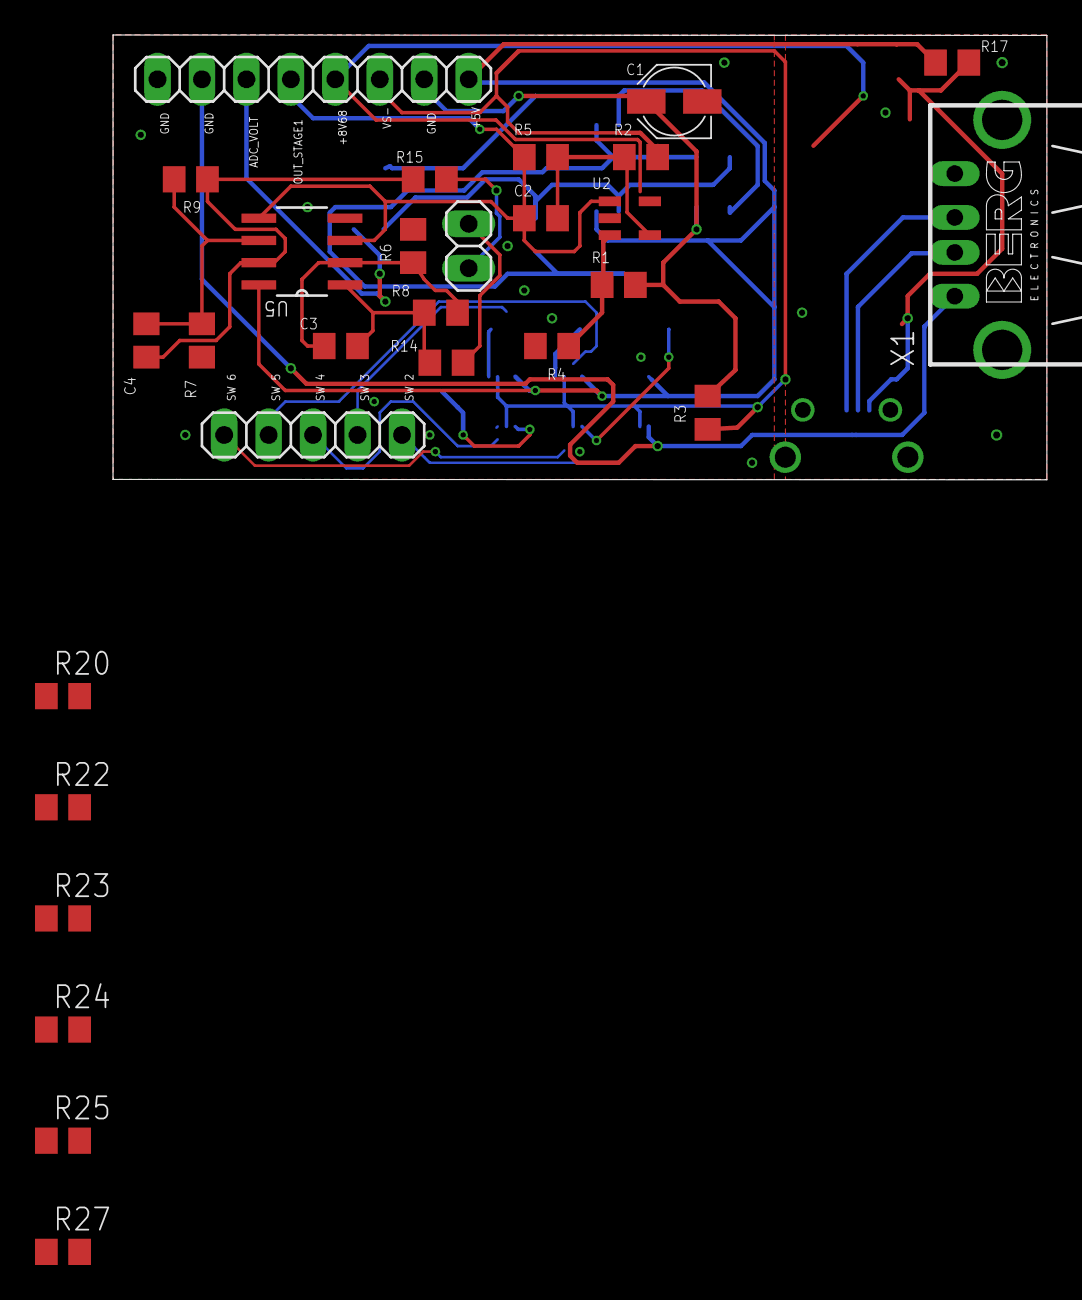
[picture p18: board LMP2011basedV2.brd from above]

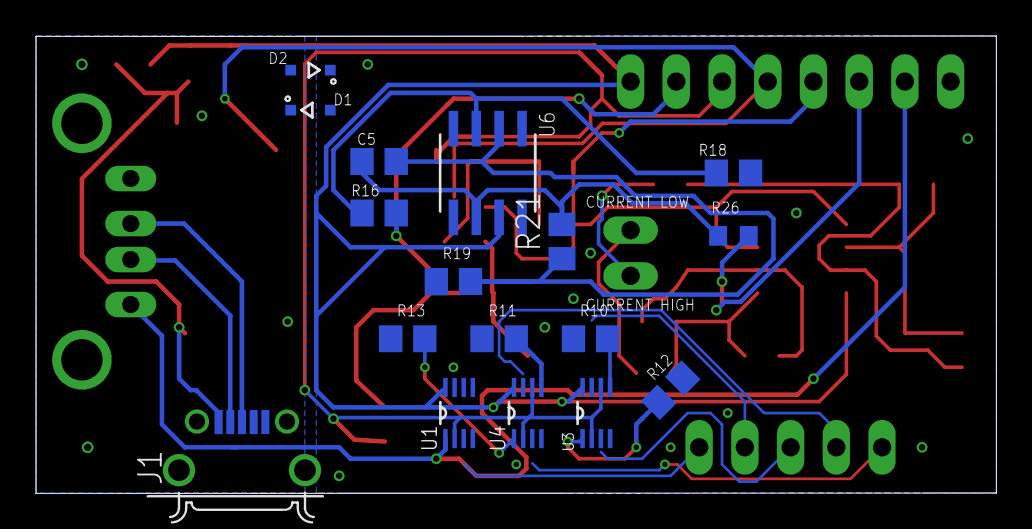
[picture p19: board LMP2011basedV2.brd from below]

Board: 2 copper layers, 53.4 x 25.4 mm, 45 parts (17 on the bottom side), 31 nets.

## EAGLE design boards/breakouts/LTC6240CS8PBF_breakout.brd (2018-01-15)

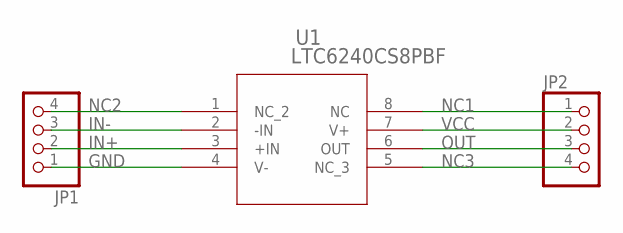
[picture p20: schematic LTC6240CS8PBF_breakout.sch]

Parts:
JP1, JP2: PINHD-1X4; 1X04
U1: LTC6240CS8PBF; SO-8_S

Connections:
GND: JP1.1, U1.4 (V-)
IN+: JP1.2, U1.3 (+IN)
IN-: JP1.3, U1.2 (-IN)
NC1: JP2.1, U1.8 (NC)
NC2: JP1.4, U1.1 (NC_2)
NC3: JP2.4, U1.5 (NC_3)
OUT: JP2.3, U1.6 (OUT)
VCC: JP2.2, U1.7 (V+)

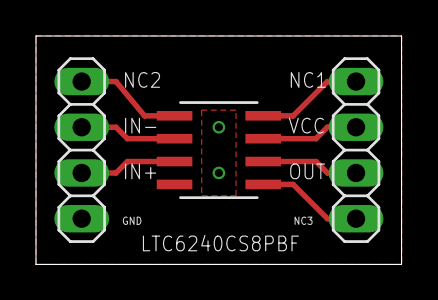
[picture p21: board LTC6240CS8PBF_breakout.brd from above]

Board: 2 copper layers, 20.3 x 12.7 mm, 3 parts (0 on the bottom side), 8 nets.

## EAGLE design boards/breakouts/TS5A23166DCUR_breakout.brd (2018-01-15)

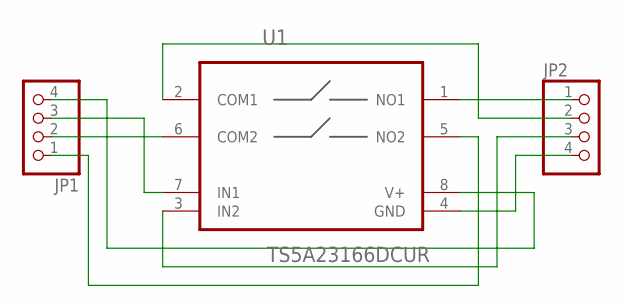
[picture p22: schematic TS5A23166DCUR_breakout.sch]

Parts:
JP1, JP2: PINHD-1X4; 1X04
U1: TS5A23166DCUR; SOP50P310X90-8N

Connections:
COM1: JP2.2, U1.2 (COM1)
COM2: JP1.2, U1.6 (COM2)
GND: JP2.4, U1.4 (GND)
IN1: JP1.3, U1.7 (IN1)
IN2: JP2.3, U1.3 (IN2)
NO1: JP2.1, U1.1 (NO1)
NO2: JP1.1, U1.5 (NO2)
VCC: JP1.4, U1.8 (V+)

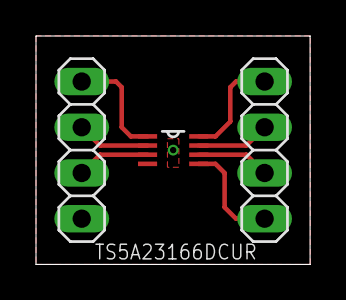
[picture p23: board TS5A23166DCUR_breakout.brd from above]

Board: 2 copper layers, 15.2 x 12.7 mm, 3 parts (0 on the bottom side), 8 nets.

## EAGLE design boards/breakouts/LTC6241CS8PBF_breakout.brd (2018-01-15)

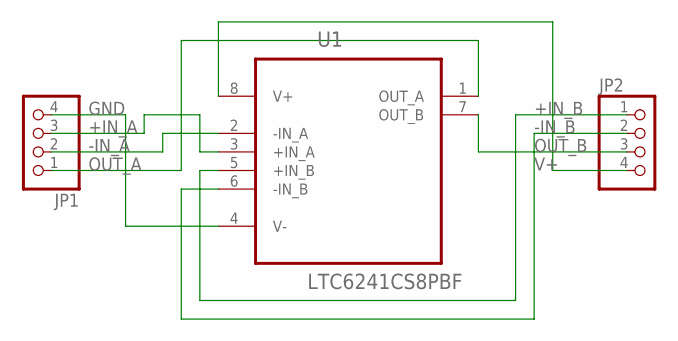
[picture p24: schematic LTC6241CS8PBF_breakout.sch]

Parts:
JP1, JP2: PINHD-1X4; 1X04
U1: LTC6241CS8PBF; SOIC127P600X175-8N

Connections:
+IN_A: JP1.3, U1.3 (+IN_A)
+IN_B: JP2.1, U1.5 (+IN_B)
-IN_A: JP1.2, U1.2 (-IN_A)
-IN_B: JP2.2, U1.6 (-IN_B)
GND: JP1.4, U1.4 (V-)
OUT_A: JP1.1, U1.1 (OUT_A)
OUT_B: JP2.3, U1.7 (OUT_B)
V+: JP2.4, U1.8 (V+)

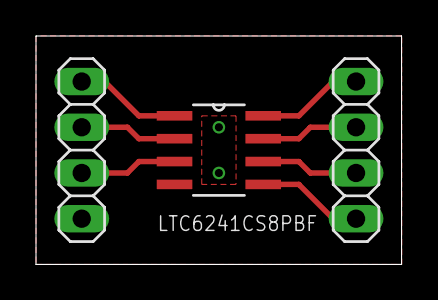
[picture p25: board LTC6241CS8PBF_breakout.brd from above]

Board: 2 copper layers, 20.3 x 12.7 mm, 3 parts (0 on the bottom side), 8 nets.

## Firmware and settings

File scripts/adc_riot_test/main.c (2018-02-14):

/**
 * @{
 *
 * @file        main.c
 * @brief       Test for RIOT's peripherial ADC intended to measure current across a shunt resistor.
 *
 * @author      Juan Pablo Futalef <juan.futalef@ing.uchile.cl>
 *
 * @}
 */

#include <stdio.h>
#include <math.h>

#include "xtimer.h"
#include "timex.h"
#include "periph/adc.h"

#define BIT_R           12      // bit resolution of ADC
#define ADC_POS_REF	    3.3     // positive voltage reference of ADC
#define SHUNT_VAL       0.45    // Shunt resistor value in ohms
#define DELAY 		      2000    // every DELAY milliseconds read a value
//#define SAMPLES_ADC   400     // take SAMPLES_ADC measures a get a mean value, comment to disable

#if BIT_R == 8
  #define RES ADC_RES_12BIT
#elif BIT_R == 10
  #define RES ADC_RES_10BIT
#elif BIT_R == 12
  #define RES ADC_RES_12BIT
#endif

void pause(int mil)
{
  uint32_t now = xtimer_usec_from_ticks(xtimer_now());
  uint32_t before = now;
  while(now-before < mil*1000.0)
  {
	now = xtimer_usec_from_ticks(xtimer_now());
  }
}

uint32_t measure(adc_t line, adc_res_t RES, int samples)
{
  uint32_t sum = 0;

  for (int i = 0; i < samples; i++) {
    sum = adc_sample(line, RES) + sum;
  }
  return sum/samples;
}

int main(void)
{
    int sample = 0;

    puts("RIOT ADC peripheral driver test for current masurement.\n");
    puts("This test will sample ADC lines 0 and 1, supposed to be connected\n"
         "to a shunt resistor and make calculations for current measurement.\n\n");

    // check if there are at least 2 ADC lines available.
    if (ADC_NUMOF < 1) {
      printf("Number of ADC lines available less than 2.\n");
    }

    else
    {
      // initialize ADC lines 0 and 1
      for (int i = 0; i < 2; i++) {
          if (adc_init(ADC_LINE(i)) < 0) {
              printf("Initialization of ADC_LINE(%u) failed\n", i);
              return 1;
          } else {
              printf("Successfully initialized ADC_LINE(%u)\n", i);
          }
      }

      // check if resolution applies to both lines
      for (int i = 0; i < 2; i++)
      {
        sample = adc_sample(ADC_LINE(i), RES);
        if (sample < 0) {
            printf("ADC_LINE(%u): %i-bit resolution not applicable\n", i, BIT_R);
            return 0;
        }
      	else
      	{
      	    printf("ADC_LINE(%u) resolution: %i\n", i, BIT_R);
      	}
      }

      // Measurement calculations
      float measurement[2];
      float shuntVoltage, shuntCurrent;
      char* v[2];
      v[0] = "Vsup";
      v[1] = "Vmcu";

      // display to user if multiple samples mean is enabled
      #ifdef SAMPLES_ADC
        printf("Samples mean enabled with %i samples.\n\n", SAMPLES_ADC);
      #else
        printf("Samples mean NOT enabled.\n\n");
      #endif

      // measure!
      while(1)
      {
        for (unsigned i = 0; i < 2; i++)
        {
          #ifdef SAMPLES_ADC
            sample = measure(ADC_LINE(i), RES, SAMPLES_ADC);
          #else
            sample = adc_sample(ADC_LINE(i), RES);
          #endif

          measurement[i] = (float)sample*ADC_POS_REF/pow(2.0, BIT_R);
	        // printf("Measure ADC_LINE(%i):  %u\n", i, sample);
          printf("%s: %.4f [V]\n", v[i], measurement[i]);
        }

        shuntVoltage = measurement[0] - measurement[1];
        shuntCurrent = shuntVoltage/(float)SHUNT_VAL;
        printf("Shunt voltaje: %.4f [mV]\n", shuntVoltage*1000.0);
        printf("Shunt current: %.4f [mA]\n\n", shuntCurrent*1000.0);
        pause(DELAY);
      }
    }

    return 0;
}

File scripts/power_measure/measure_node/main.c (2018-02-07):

#include <stdio.h>

#include "shell.h"
#include "msg.h"

#define MAIN_QUEUE_SIZE     (8)
static msg_t _main_msg_queue[MAIN_QUEUE_SIZE];

extern int measure_cmd(int argc, char **argv);
extern int start_up(void);

static const shell_command_t shell_commands[] = {
    { "meas", "configure current measurement", measure_cmd },
    { NULL, NULL, NULL }
};

int main(void)
{
    msg_init_queue(_main_msg_queue, MAIN_QUEUE_SIZE);

    if(start_up()){
        puts("error: not enough adc lines on this mcu");
        return 1;
    }

    puts("All up, running the shell now");
    char line_buf[SHELL_DEFAULT_BUFSIZE];
    shell_run(shell_commands, line_buf, SHELL_DEFAULT_BUFSIZE);

    return 0;
}

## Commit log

2018-01-15 PCB layouts
    [LMP2011basedV1.brd, LMP2011basedV1.sch, LTC6240CS8PBF_breakout.brd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]
2018-01-23 RIOT, new PCB layouts and scripts
    [LMP2011basedV2.brd, LMP2011basedV2.sch, MAX4239basedV3.brd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]
2018-01-31 spice models, scripts and pcb layouts update
    [LMP2011basedV2.brd, LMP2011basedV2.sch, MAX4239basedV3.brd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]
2018-01-31 readme for script in power_measure
2018-01-31 Added stage images for MAX4239 circuit and README
    nuevo archivo: pcb_layout/PCB/LMP2011/README.md
    nuevo archivo: pcb_layout/PCB/MAX4239/Images/IM1.png
    nuevo archivo: pcb_layout/PCB/MAX4239/Images/IM2.png
    nuevo archivo: pcb_layout/PCB/MAX4239/Images/IM3.png
    nuevo archivo: pcb_layout/PCB/MAX4239/Images/IM4.png
    nuevo archivo: pcb_layout/PCB/MAX4239/Images/IM5.png
    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
    [MAX4239basedV3.brd, MAX4239basedV3.sch]
2018-01-31 Added figures for LMP2011
    [LMP2011basedV2.brd, LMP2011basedV2.sch]
2018-02-05 reorder directories
    [LMP2011basedV1.brd, LMP2011basedV1.sch, LMP2011basedV2.brd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]
2018-02-05 apply styling, modify readmes
    [LTC6240CS8PBF_breakout.brd, LTC6240CS8PBF_breakout.sch, LTC6241CS8PBF_breakout.brd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]
2018-02-07 Readme updato for PCB folder, MAX4239, scripts folder and added ltspice README.
2018-02-07 Readme update for PCB folder, MAX4239, scripts folder and added ltspice README.
2018-02-07 Added spice models for MAX4239 & LMP2011 in ltspice/Spice Models. In the same directory, created a readme file about them. Update PCB readme file, MAX4239 figures directory, MAX4239 readme file, scri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
2018-02-08 name styling, wip on translating some doc
    [LMP2011basedV1.brd, LMP2011basedV1.sch, LMP2011basedV2.brd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]
2018-02-14 Add author to scripts in adc_riot_test, arduino_ina226 and master.py in power_measure. Add photos of prototiped board
